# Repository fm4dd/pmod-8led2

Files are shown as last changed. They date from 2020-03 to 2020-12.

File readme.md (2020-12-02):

## 8LED2 PMOD

### Description

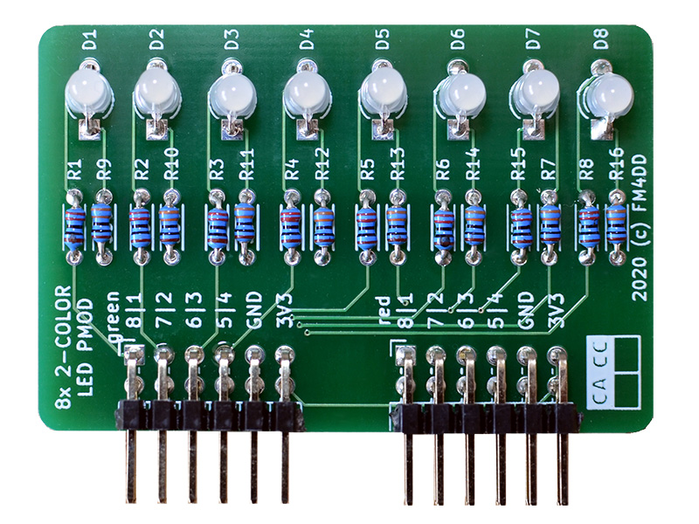
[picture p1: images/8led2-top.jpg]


This PMOD provides 8x dual-color LED display output to FPGA designs via two double row PMODs.
It is possible to install either type of dual-color LEDs: "common cathode" or "common anode". The default is "common cathode", which allows for working with normal logic. With normal logic, setting the output "HIGH" lights up the LED. If "common anode" LEDs are installed, JP1 must separate GND, and close the connection to + 3.3V. Common anode uses inverted logic, The LEDs light up when the output is set "LOW".
[fpga.fm4dd.com](http://fpga.fm4dd.com/)

### Schematic
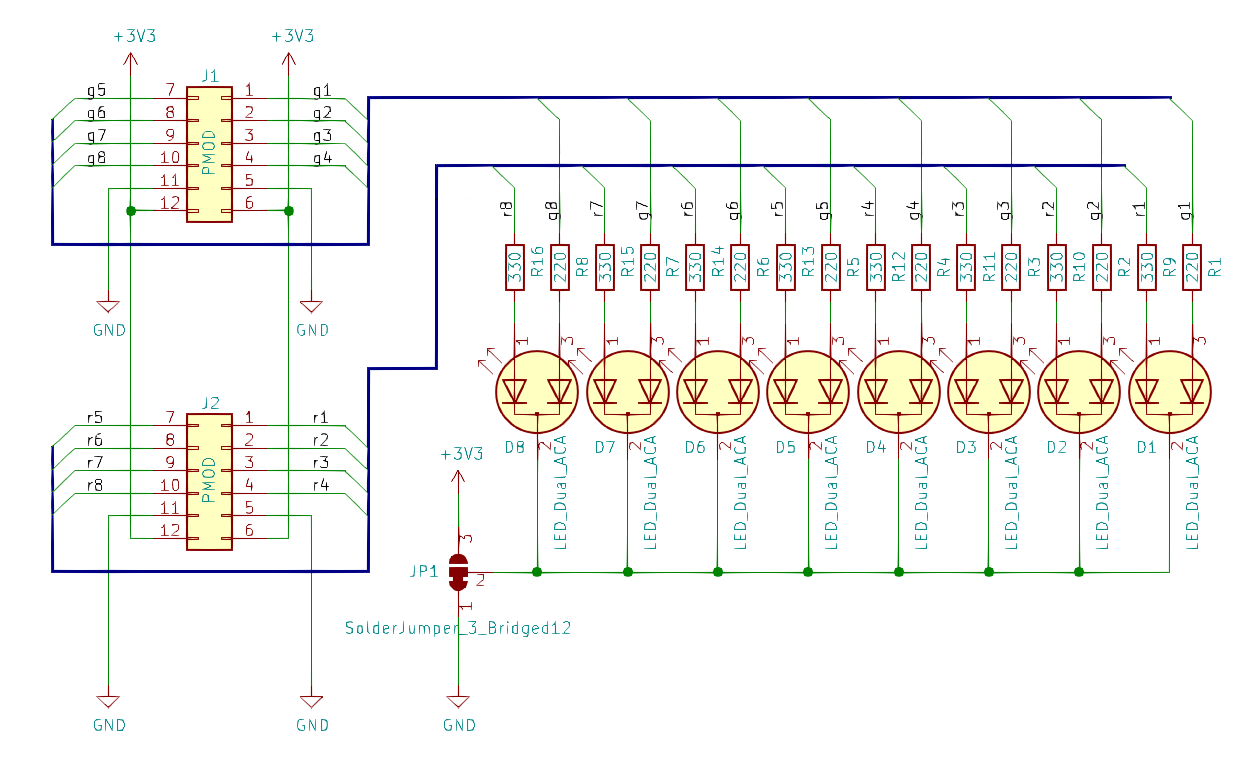
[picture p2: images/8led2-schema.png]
8LED2 PMOD Schematics


### PCB Gerber

[8LED2 PMOD Gerber V1.0](20200206-8led2-gerber-v10.zip)

### Pin Assignments

#### IceBreaker v1.0

 J1# |  Label | Description   | PMOD1A
-----|--------|---------------|-------
1    |  D1    | LED D1 green  | 4
2    |  D2    | LED D2 green  | 2
3    |  D3    | LED D3 green  | 47
4    |  D4    | LED D4 green  | 45
7    |  D5    | LED D5 green  | 3
8    |  D6    | LED D6 green  | 48
9    |  D7    | LED D7 green  | 46
10   |  D8    | LED D8 green  | 44

 J2# |  Label | Description   | PMOD1B
-----|--------|---------------|-------
1    |  D1    | LED D1 red    | 43
2    |  D2    | LED D2 red    | 38
3    |  D3    | LED D3 red    | 34
4    |  D4    | LED D4 red    | 31
7    |  D5    | LED D5 red    | 42
8    |  D6    | LED D6 red    | 36
9    |  D7    | LED D7 red    | 32
10   |  D8    | LED D8 red    | 28

#### DE0-Nano-SoC

The connection to Intels DE0-Nano-SoC is made through the pmod2nano adapter.

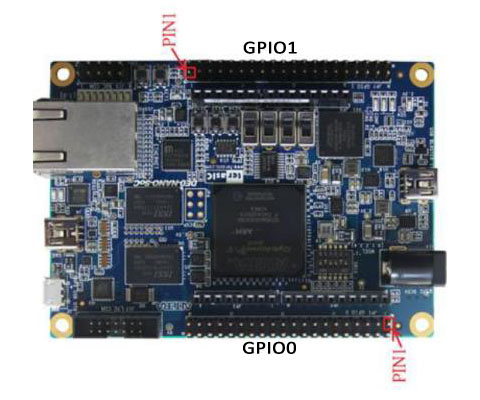
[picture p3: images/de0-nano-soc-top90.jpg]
DE0-Nano-SoC


 J1# |  Label | Description   | GPIO0A | GPIO1A
-----|--------|---------------|--------|--------
1    |  D1    | LED D1 green  | PIN_AF8|PIN_AH27
2    |  D2    | LED D2 green  | PIN_AB4|PIN_AH24
3    |  D3    | LED D3 green  | PIN_Y4 |PIN_AE22
4    |  D4    | LED D4 green  | PIN_U11|PIN_AG20
7    |  D5    | LED D5 green  | PIN_W12|PIN_AA15
8    |  D6    | LED D6 green  | PIN_Y8 |PIN_AG26
9    |  D7    | LED D7 green  | PIN_W8 |PIN_AF23
10   |  D8    | LED D8 green  | PIN_Y5 |PIN_AF21

 J2# |  Label | Description   | GPIO0B | GPIO1B
-----|--------|---------------|--------|--------
1    |  D1    | LED D1 red    | PIN_AG6| PIN_AG23
2    |  D2    | LED D2 red    | PIN_AE4| PIN_AF18
3    |  D3    | LED D3 red    | PIN_T11| PIN_AE20
4    |  D4    | LED D4 red    | PIN_AF6| PIN_AD20
7    |  D5    | LED D5 red    | PIN_AF4| PIN_AH23
8    |  D6    | LED D6 red    | PIN_AF5| PIN_AE19
9    |  D7    | LED D7 red    | PIN_T13| PIN_AD19
10   |  D8    | LED D8 red    | PIN_AE7| PIN_AE24

### Example Code

#### Verilog

Verilog test program pmod8led2_1.v (top-level):
```
// -------------------------------------------------------
// This program tests HW pin assignment, and lights up D1
//--------------------------------------------------------
module pmod8led2_1 (
  output [0:7] pmodledr
);

  reg led;
  assign pmodledr[7] = led;

  always
  begin
    led = 1'b1;  // light up D1
  end
endmodule
```

Verilog test program pmod8led2_2.v (top-level):
```
// -------------------------------------------------------
// This program is a binary counter, displayed on the pmod
// LED D2-8 green color. The 1Hz clock pulse is on D1 red.
// 12MHz clock: set breakpoint at 23'd5999999 (icebreaker)
// 50MHz clock: set breakpoint at 25'd24999999 (de0-nano)
//--------------------------------------------------------
module pmod8led2_2 (
  input clk,
  output reg [0:7] pmodledg,
  output reg [0:7] pmodledr
);

  reg clk_1hz = 1'b0;
  reg [22:0] count = 23'd0;
  reg [6:0] lednum = 7'd0;
  assign [1:7] pmodledg = lednum;
  assign [1:7] pmodledr = 7'b0000000;
  assign pmodledr[0] = clk_1hz;

  always @(posedge clk)
  begin
    count   <= count + 1;
    if(count == 23'd5999999)
    begin
      count   <= 0;
      clk_1hz <= ~clk_1hz;
      lednum  <= lednum + 1;
    end
  end
endmodule
```

#### VHDL

The Verilog example pmod8led2_2.v converted to VHDL as pmod8led2_3.vhd:

```
-- -------------------------------------------------------
-- This program is a binary counter, displayed on the pmod
-- LED D1-7 green color. The 1Hz clock pulse is on D8 red.
-- 12MHz clock: set breakpoint at 23'd5999999 (icebreaker)
-- 50MHz clock: set breakpoint at 25'd24999999 (de0-nano)
-- 25MHz clock: set breakpoint at 24'd12499999 (ulx3s)
-- -------------------------------------------------------
library ieee;
use ieee.std_logic_1164.all;
use ieee.numeric_std.all;

entity pmod_8led2_3 is
port (
       clk: in STD_LOGIC;
  pmodledg: out STD_LOGIC_VECTOR(0 to 7) := "00000000";
  pmodledr: out STD_LOGIC_VECTOR(0 to 7) := "00000000"
);
end pmod_8led2_3;

architecture arch of pmod_8led2_3 is
  signal clk_1hz: STD_LOGIC := '0';

  begin
    counter_p: process( clk, clk_1hz )
    variable count: INTEGER := 0;
    variable lednum: STD_LOGIC_VECTOR(6 downto 0) := "0000000";
    begin
      if( rising_edge(clk) ) then
             count := count + 1;
        if( count = 5999999 ) then
               count := 0;
               clk_1hz <= NOT clk_1hz;
               lednum  := std_logic_vector( unsigned(lednum) + 1);
        end if;
           end if;

    pmodledr <= (0 => clk_1hz, others => '0');
    pmodledg(0) <= '0';
    pmodledg(1) <= lednum(6);
    pmodledg(2) <= lednum(5);
    pmodledg(3) <= lednum(4);
    pmodledg(4) <= lednum(3);
    pmodledg(5) <= lednum(2);
    pmodledg(6) <= lednum(1);
    pmodledg(7) <= lednum(0);

  end process counter_p;
end arch;
```

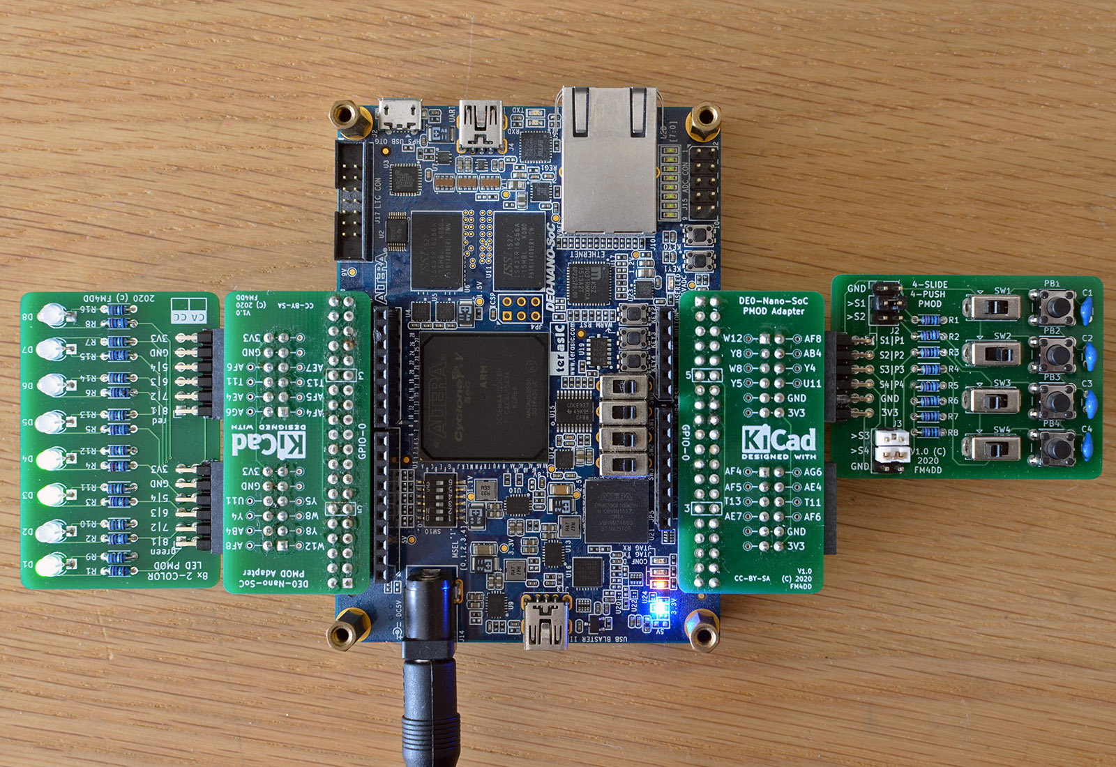
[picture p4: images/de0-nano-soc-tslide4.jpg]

8LED2 PMOD on a DE0-Nano-SoC board

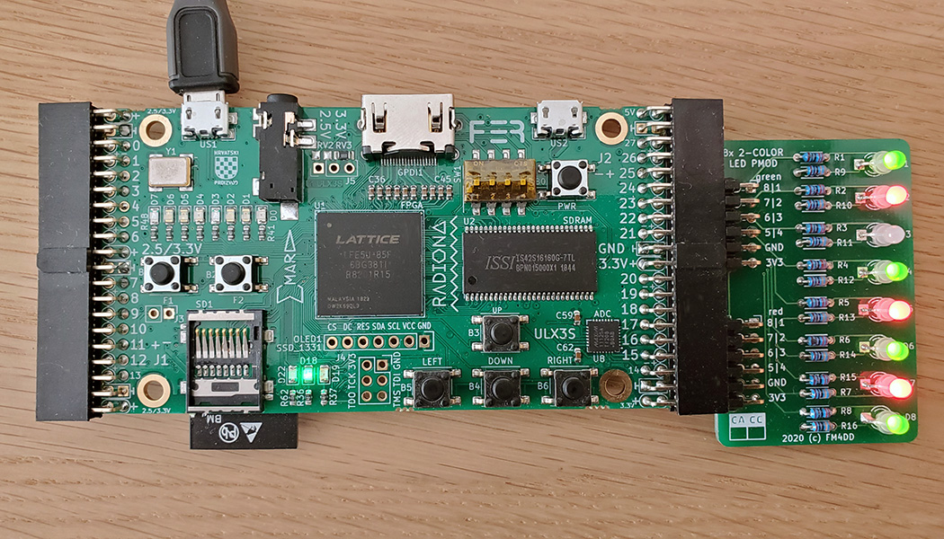
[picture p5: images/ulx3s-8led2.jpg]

8LED2 PMOD on a ULX3S Lattice ECP 85K board

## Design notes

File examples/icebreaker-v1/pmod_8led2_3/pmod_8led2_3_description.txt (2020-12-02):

This program is a binary counter, demonstrating the function of the 8LED2 PMOD under VHDL.

The functionality has been converted from the Verilog program pmod_8led2_2.v. It has been tested on a Icebreaker and ULX3S board, using the Linux open source workflow (yosys, nextpnr, icestorm and fujprog for the board-specific programming). The yosys GHDL synthesis works fine on the VHDL code.

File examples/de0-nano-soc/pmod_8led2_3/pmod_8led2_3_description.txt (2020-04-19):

This program is a binary counter, demonstrating the function of the 8LED2 PMOD under VHDL. 

The functionality has been converted from the Verilog program pmod_8led2_2.v, tested on a Icebreaker v1.0 board, using the Linux open source workflow (yosys, nextpnr, and icestorm). Without an open source VHDL workflow, I am testing VHDL on a DE0-Nano-SoC board with Quartus Prime Version 17.1 Lite Edition on Windows.

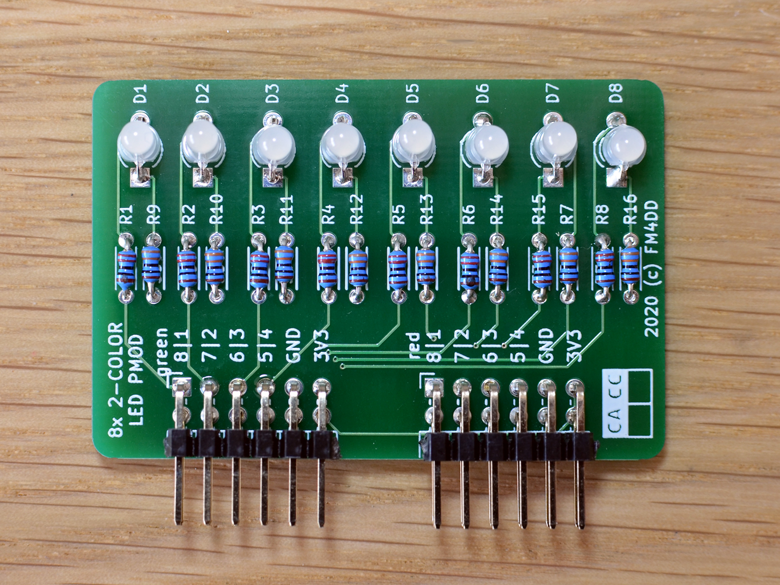
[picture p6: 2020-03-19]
images/fm4dd-pmod-8led2-1600x1200.jpg

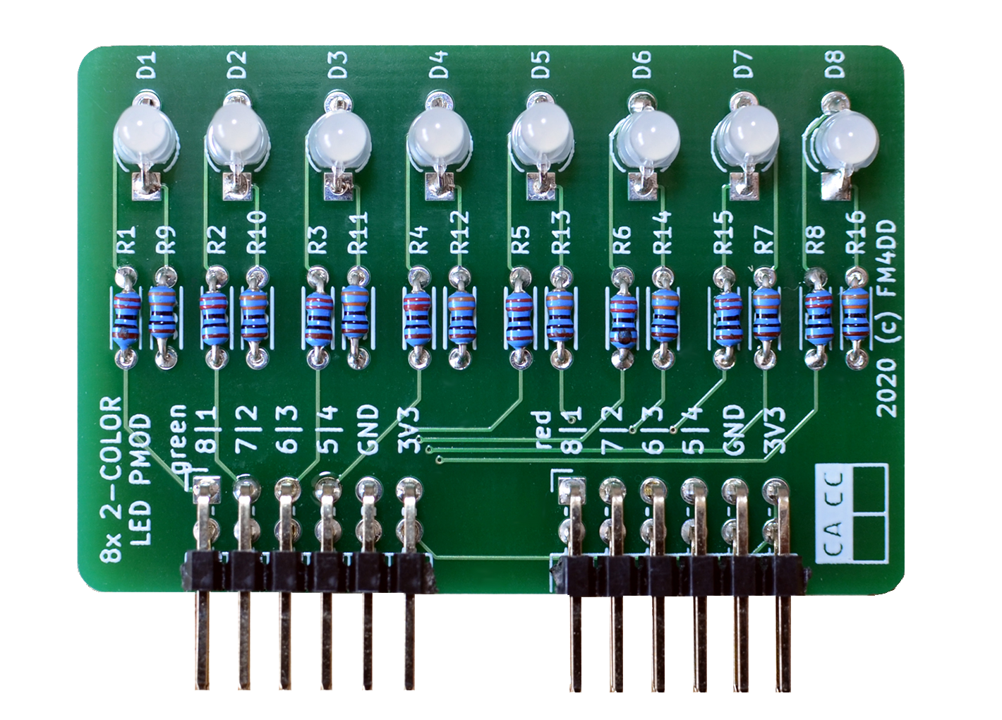
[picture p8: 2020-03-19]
images/fm4dd-pmod-8led2-1420x1020.png

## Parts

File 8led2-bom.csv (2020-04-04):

Manufacturer Part Number | Manufacturer | Digi-Key Part Number | Reference | Quantity | Description
RNMF14FTC220R | Stackpole Electronics Inc | S220CACT-ND | R1-8 | 8 | RES 220 OHM 1/4W 1% AXIAL for LED green
RNMF14FTC330R | Stackpole Electronics Inc | S330CACT-ND | R9-16 | 8 | RES 330 OHM 1/4W 1% AXIAL for LED red
OSRGHC3132A | OptoSupply | N/A | D1-D8 | 8 | 3mm Round Red & Green LED Common Cathode
PEC20DBAN | Sullins Connector Solutions | S2112E-20-ND | J1,J2 | 1 | CONN HEADER R/A 40POS 2.54MM cut to size

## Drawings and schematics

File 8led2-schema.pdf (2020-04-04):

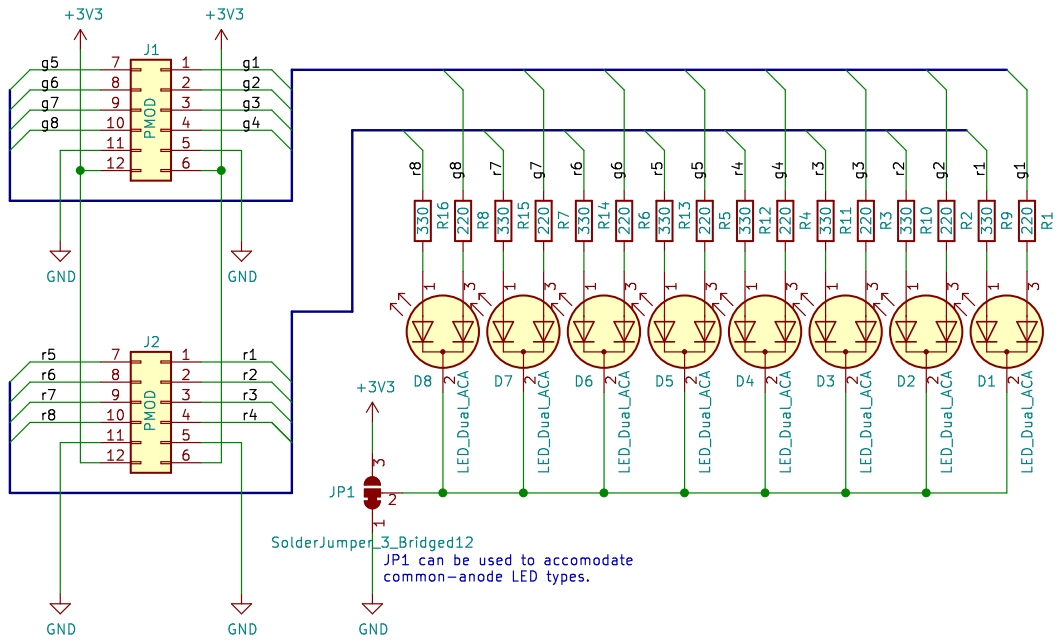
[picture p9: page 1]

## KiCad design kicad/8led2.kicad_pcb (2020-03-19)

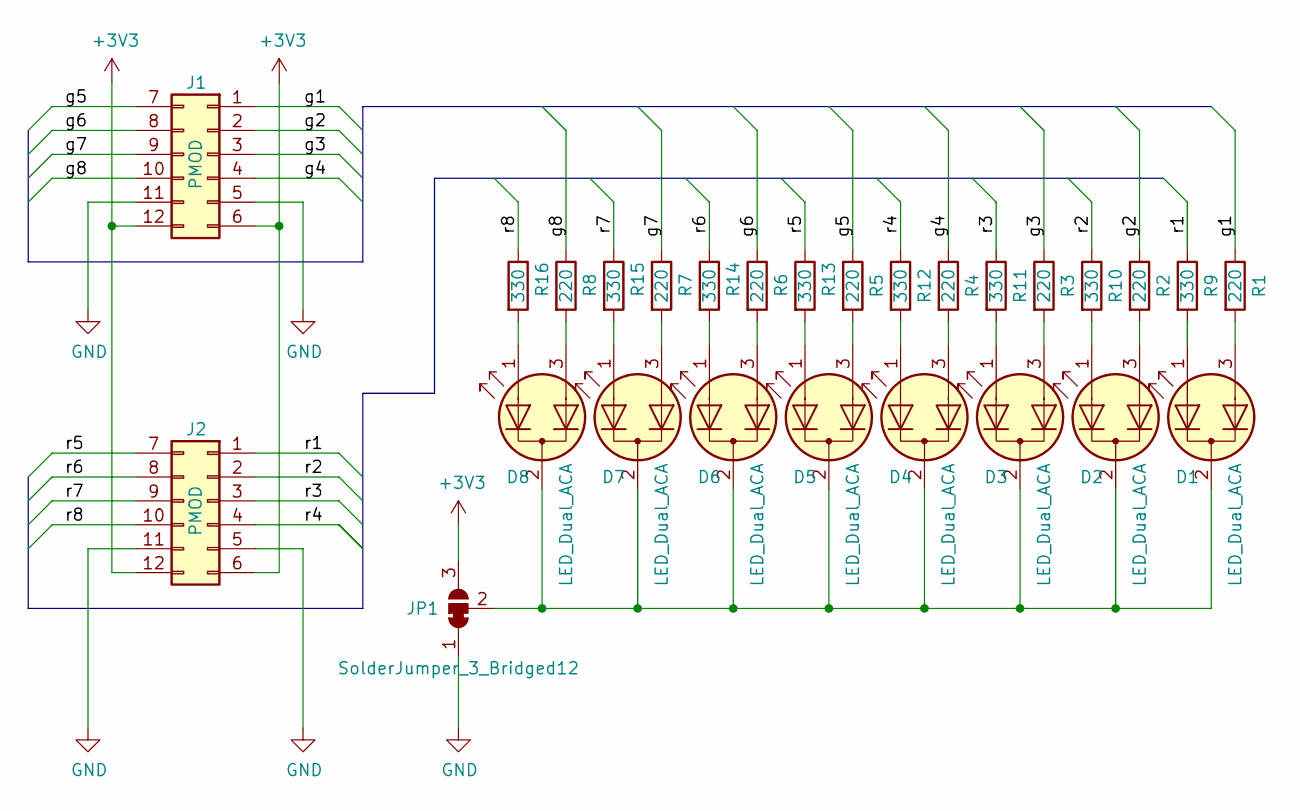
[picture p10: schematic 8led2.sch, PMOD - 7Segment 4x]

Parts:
D1, D2, D3, D4, D5, D6, D7, D8: LED_Dual_ACA; LED_D3.0mm-3
J1, J2: PMOD; PMODHeader_2x06_P2.54mm_Horizontal
JP1: SolderJumper_3_Bridged12; SolderJumper-3_P1.3mm_Bridged2Bar12_Pad1.0x1.5mm
R1, R2, R3, R4, R5, R6, R7, R8: 220; R_Axial_DIN0204_L3.6mm_D1.6mm_P5.08mm_Horizontal
R9, R10, R11, R12, R13, R14, R15, R16: 330; R_Axial_DIN0204_L3.6mm_D1.6mm_P5.08mm_Horizontal

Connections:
+3V3: J1.6, J1.12, J2.6, J2.12, JP1.3 (B)
/g1: J1.1, R1.1
/g2: J1.2, R2.1
/g3: J1.3, R3.1
/g4: J1.4, R4.1
/g5: J1.7, R5.1
/g6: J1.8, R6.1
/g7: J1.9, R7.1
/g8: J1.10, R8.1
/r1: J2.1, R9.1
/r2: J2.2, R10.1
/r3: J2.3, R11.1
/r4: J2.4, R12.1
/r5: J2.7, R13.1
/r6: J2.8, R14.1
/r7: J2.9, R15.1
/r8: J2.10, R16.1
GND: J1.5, J1.11, J2.5, J2.11, JP1.1 (A)
unnamed: D1.1 (A1), R9.2
unnamed: D1.2 (K), D2.2 (K), D3.2 (K), D4.2 (K), D5.2 (K), D6.2 (K), D7.2 (K), D8.2 (K), JP1.2 (C)
unnamed: D1.3 (A2), R1.2
unnamed: D2.1 (A1), R10.2
unnamed: D2.3 (A2), R2.2
unnamed: D3.1 (A1), R11.2
unnamed: D3.3 (A2), R3.2
unnamed: D4.1 (A1), R12.2
unnamed: D4.3 (A2), R4.2
unnamed: D5.1 (A1), R13.2
unnamed: D5.3 (A2), R5.2
unnamed: D6.1 (A1), R14.2
unnamed: D6.3 (A2), R6.2
unnamed: D7.1 (A1), R15.2
unnamed: D7.3 (A2), R7.2
unnamed: D8.1 (A1), R16.2
unnamed: D8.3 (A2), R8.2

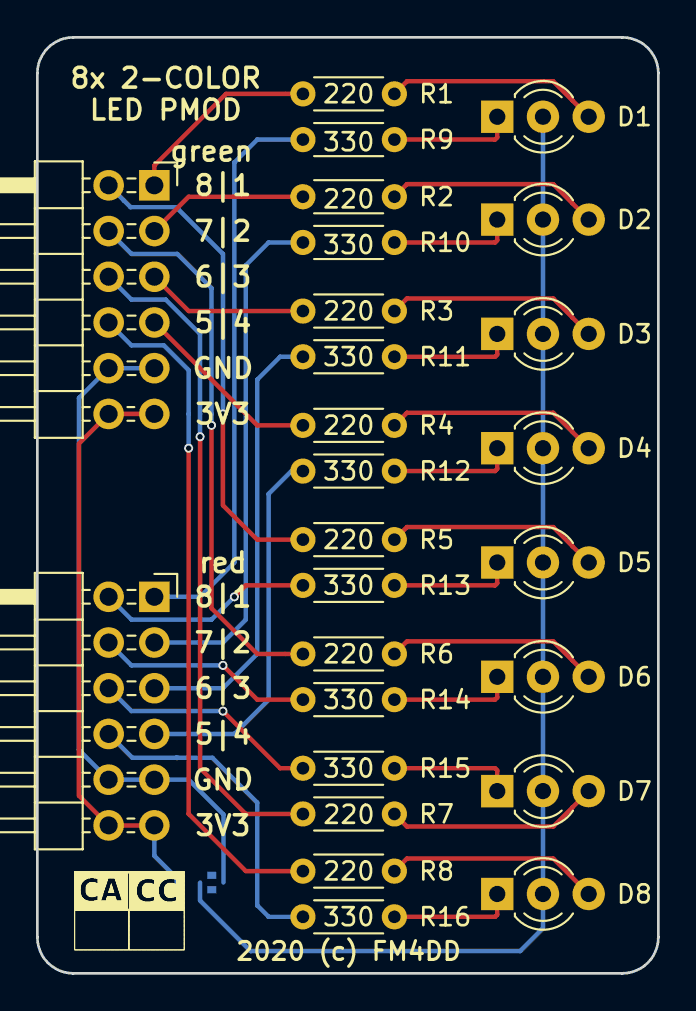
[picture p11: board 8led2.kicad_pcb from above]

Board: 2 copper layers, 34.5 x 52.0 mm, 28 parts (1 on the bottom side), 35 nets.

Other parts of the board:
7seg-type-display: 7seg-type-display

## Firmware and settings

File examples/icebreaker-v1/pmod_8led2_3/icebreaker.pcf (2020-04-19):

# 12 MHz clock
set_io -nowarn clk        35

# RS232
set_io -nowarn RX          6
set_io -nowarn TX          9

# LEDs and Button
set_io -nowarn BTN_N      10
set_io -nowarn LEDR_N     11
set_io -nowarn LEDG_N     37

# RGB LED Driver
set_io -nowarn LED_RED_N  39
set_io -nowarn LED_GRN_N  40
set_io -nowarn LED_BLU_N  41

# SPI Flash
set_io -nowarn FLASH_SCK  15
set_io -nowarn FLASH_SSB  16
set_io -nowarn FLASH_IO0  14
set_io -nowarn FLASH_IO1  17
set_io -nowarn FLASH_IO2  12
set_io -nowarn FLASH_IO3  13

# PMOD 1A
#set_io -nowarn P1A1        4
#set_io -nowarn P1A2        2
#set_io -nowarn P1A3       47
#set_io -nowarn P1A4       45
#set_io -nowarn P1A7        3
#set_io -nowarn P1A8       48
#set_io -nowarn P1A9       46
#set_io -nowarn P1A10      44
set_io -nowarn pmodledg[0]  4
set_io -nowarn pmodledg[1]  2
set_io -nowarn pmodledg[2] 47
set_io -nowarn pmodledg[3] 45
set_io -nowarn pmodledg[4]  3
set_io -nowarn pmodledg[5] 48
set_io -nowarn pmodledg[6] 46
set_io -nowarn pmodledg[7] 44

# PMOD 1B
#set_io -nowarn P1B1       43
#set_io -nowarn P1B2       38
#set_io -nowarn P1B3       34
#set_io -nowarn P1B4       31
#set_io -nowarn P1B7       42
#set_io -nowarn P1B8       36
#set_io -nowarn P1B9       32
#set_io -nowarn P1B10      28
set_io -nowarn pmodledr[0] 43
set_io -nowarn pmodledr[1] 38
set_io -nowarn pmodledr[2] 34
set_io -nowarn pmodledr[3] 31
set_io -nowarn pmodledr[4] 42
set_io -nowarn pmodledr[5] 36
set_io -nowarn pmodledr[6] 32
set_io -nowarn pmodledr[7] 28

# PMOD 2
set_io -nowarn P2_1       27
set_io -nowarn P2_2       25
set_io -nowarn P2_3       21
set_io -nowarn P2_4       19
set_io -nowarn P2_7       26
set_io -nowarn P2_8       23
set_io -nowarn P2_9       20
set_io -nowarn P2_10      18

# LEDs and Buttons (PMOD 2)
set_io -nowarn LED[0]      26
set_io -nowarn LED[1]      27
set_io -nowarn LED[2]      25
set_io -nowarn LED[3]      23
set_io -nowarn LED[4]      21
set_io -nowarn SW[0]      20
set_io -nowarn SW[1]      19
set_io -nowarn SW[2]      18

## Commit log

2020-04-02 fix pin assignment and add VHDL example
2020-04-04 update schema, add BOM
    [8led2.sch]

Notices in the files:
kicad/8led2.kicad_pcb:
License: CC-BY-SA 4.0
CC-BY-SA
